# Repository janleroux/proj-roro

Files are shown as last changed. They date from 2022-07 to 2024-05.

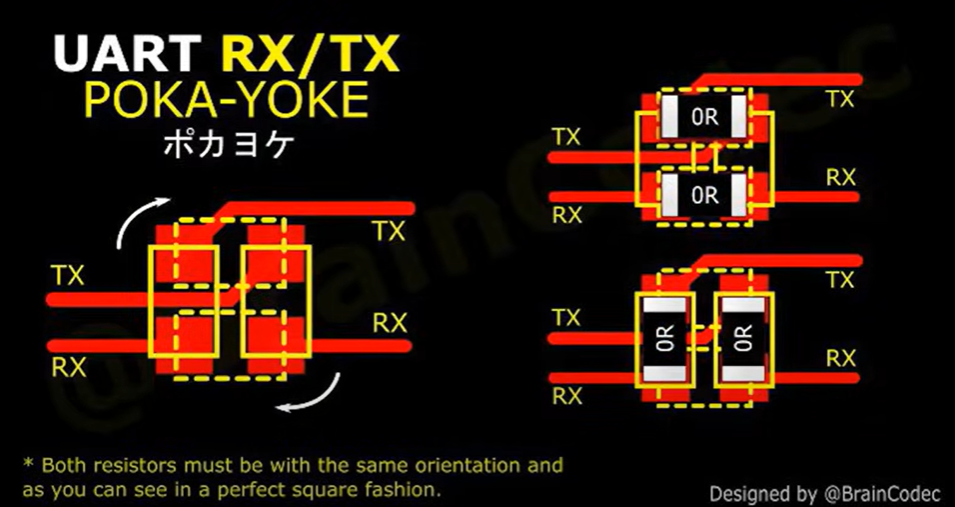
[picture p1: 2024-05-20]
linki/linki 1.0/media/Uart_mixups_fix.png

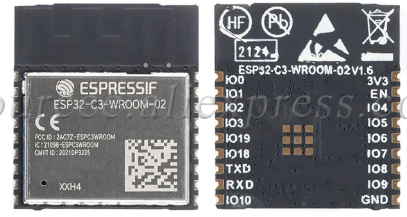
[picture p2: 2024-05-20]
linki/linki 1.0/media/WROOM-02-H4.png

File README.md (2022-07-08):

# RORO10

## Overview
The LERU Roro v1.0 is a small wireless transceiver module offers a comprehensive mix of long range, low power consumption and secure data transmission.It is designed to facilitate developers to quickly move the same platform they use for prototyping to industrial level LoRa and IoT solutions. It offers all the core functions that will solve 99% of the requirements to turn an idea to reality. It is easy to program, create and connect your things everywhere. 

The Roro wireless part is based on a RFM95 module which allows the user to send data and reach extremely long ranges at low data-rates. It provides ultra-long range spread spectrum communication and high interference immunity whilst minimising current consumption. It targets professional wireless sensor network applications such as irrigation systems, smart metering, smart cities, smartphone detection, building automation, to name a few.

Roro's mcu part use an ESP32 module from Espressif Systems. The ESP32 is a well known, widely used ultra-low-power microcontroller that incorporate connectivity options such as Wi-Fi and Bluetooth. It offers two CPU cores that can be individually controlled,and the CPU clock frequency is adjustable from 80 MHz to 240 MHz. The chip also has a low-powerco-processor that can be used instead of the CPU to save power while performing tasks that do not require muchcomputing power, such as monitoring of peripherals. ESP32 integrates a rich set of peripherals, ranging fromcapacitive touch sensors, Hall sensors, SD card interface, Ethernet, high-speed SPI, UART, I²S and I²C

[Roro Wiki](https://github.com/janleroux/leru-roro/wiki)

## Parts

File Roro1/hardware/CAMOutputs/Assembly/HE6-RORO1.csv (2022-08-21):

Qty | Value | Device | Package | Parts | Description
1 |  | CONN_01PTH_NO_SILK_YES_STOP | 1X01_NO_SILK | J1 | Single connection point. Often used as Generic Header-pin footprint for 0.1 inch spaced/style header connections
2 |  | CONN_14NO_SILK | 1X14_NO_SILK | J3, J4 | Multi connection point. Often used as Generic Header-pin footprint for 0.1 inch spaced/style header connections
1 |  | MICROBUILDER_ANTENNA_U.FL | MICROBUILDER_U.FL | ANT | U.FL Antenna Connector
1 |  | RFM69HCW_SMT | RFMHCW_SMT | U1 | RFM69HCW - ISM Band RF Transceiver
4 | 100k | RES0805-RES | RES | R1, R3, R4, R9 | Resistor
3 | 100nF | CAP0805 | CAP | C10, C11, C12 | Capacitor
2 | 10K | RES0805-RES | RES | R2, R5 | Resistor
1 | 10uF | CAP0805 | CAP | C2 | Capacitor
1 | 1nF | CAP0805 | CAP | C1 | Capacitor
1 | 22uF | CAP0805 | CAP | C9 | Capacitor
1 | ESP32-WROOM-32(8MB) | ESP32-WROOM-32(8MB) | MODULE_ESP32-WROOM-32(8MB) | U3 | WIFI MODULE 64 MBITS SPI FLASH
1 | LERU_LOGO_9MM | LERU_LOGO_9MM | LERU_LOGO_9MM | U$9
1 | MBR120 | DIODESOD123 | DIODE | D2 | DIODE
2 | MOMENTARY-SWITCH-SPST-SMD-RIGHT-ANGLE | MOMENTARY-SWITCH-SPST-SMD-RIGHT-ANGLE | TACTILE_SWITCH_SMD_RIGHT_ANGLE | PGM, RST | Momentary Switch (Pushbutton) - SPST
1 | WS2812B | WS2812B | WS2812B | NEO | WS2812B SMD addressable RGB LED

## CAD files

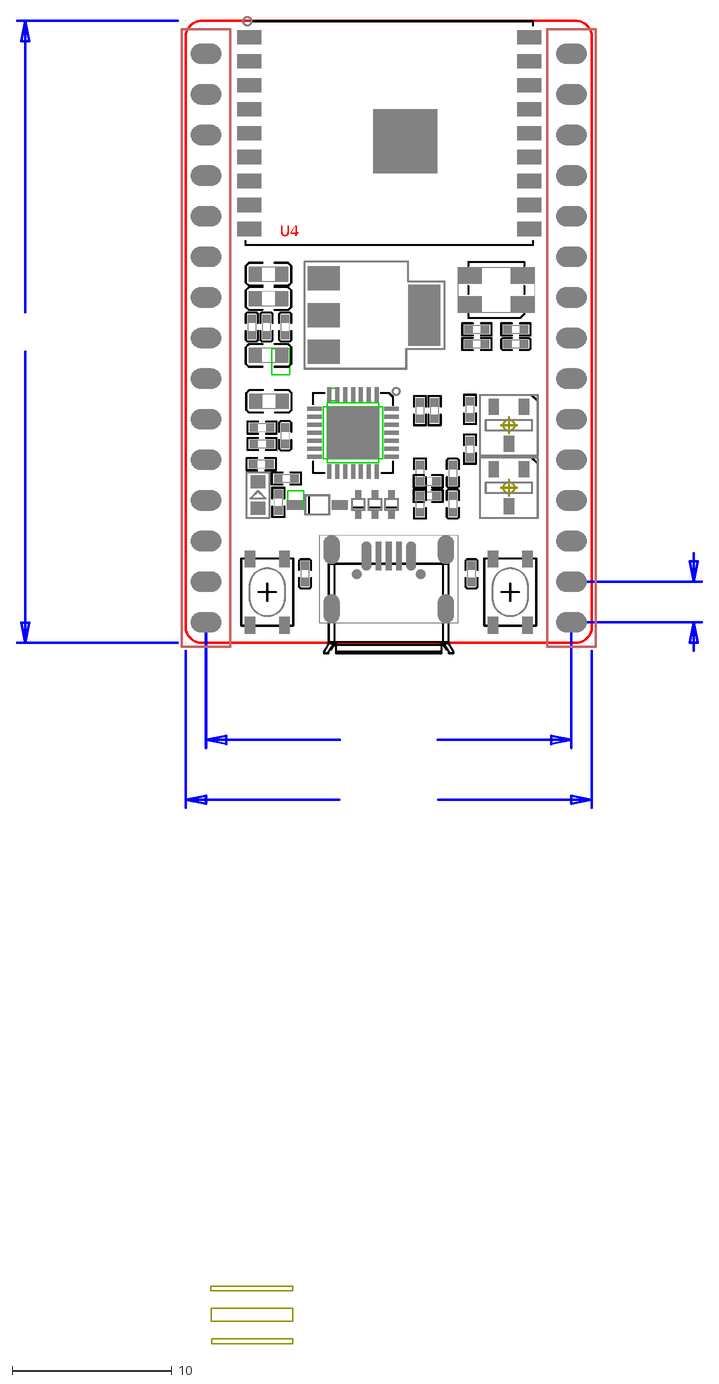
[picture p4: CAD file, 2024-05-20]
linki/linki 1.0/media/DXF_ESP32-C3-DevKitC-02_V1_1_20210121AA.dxf
U4

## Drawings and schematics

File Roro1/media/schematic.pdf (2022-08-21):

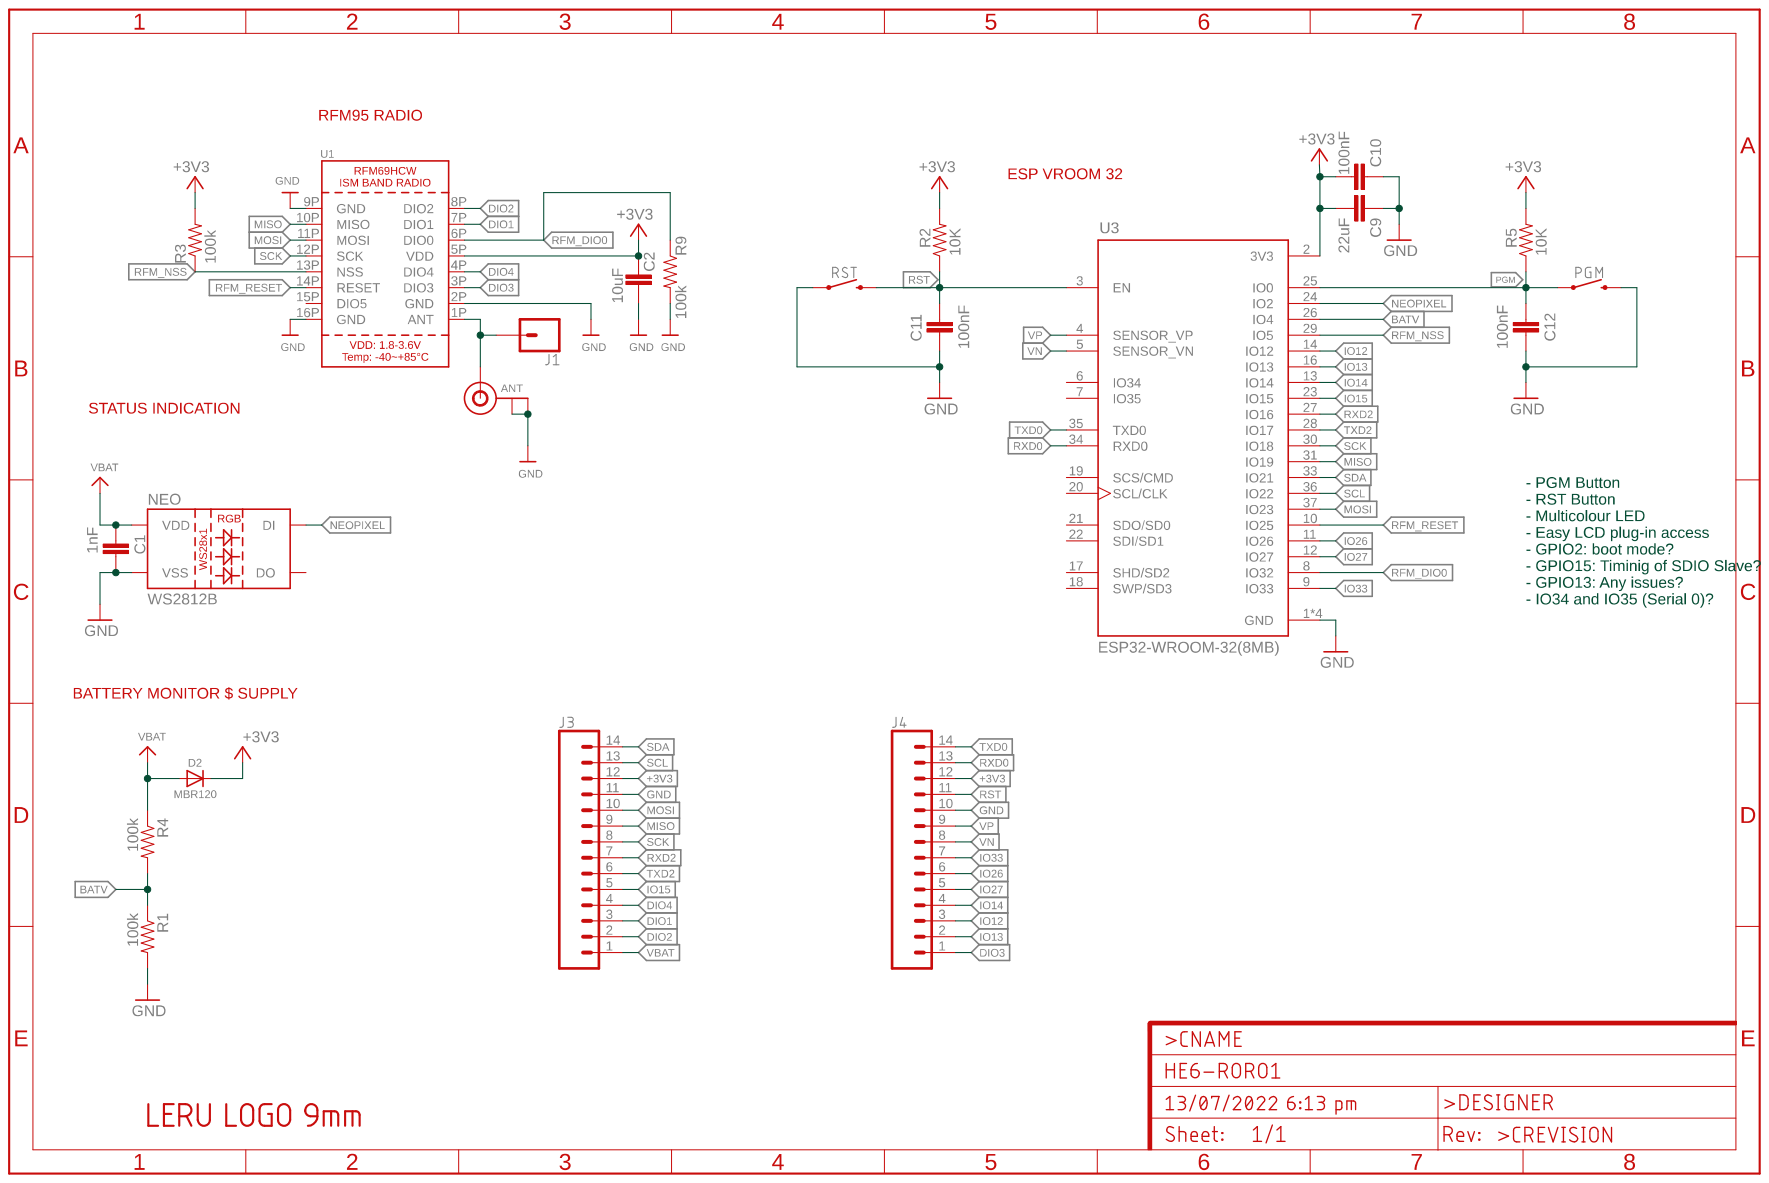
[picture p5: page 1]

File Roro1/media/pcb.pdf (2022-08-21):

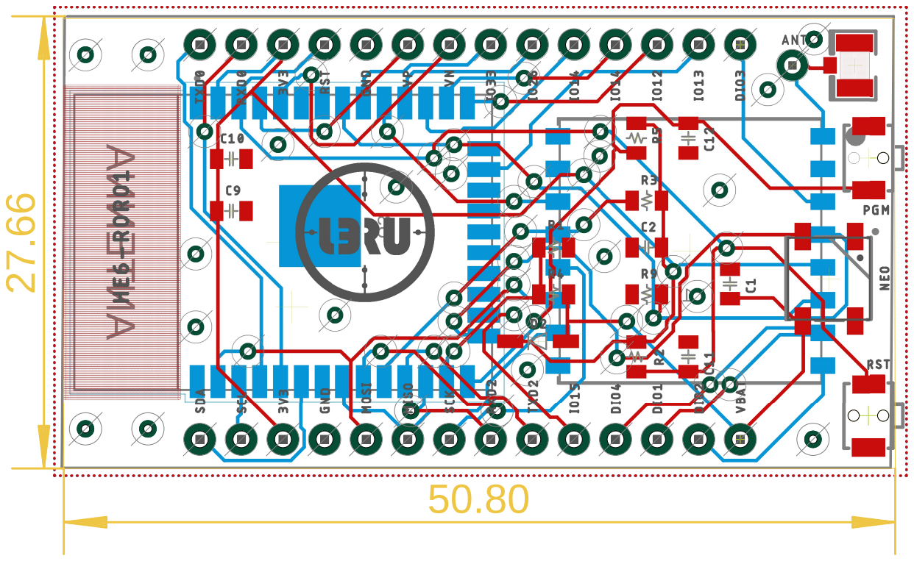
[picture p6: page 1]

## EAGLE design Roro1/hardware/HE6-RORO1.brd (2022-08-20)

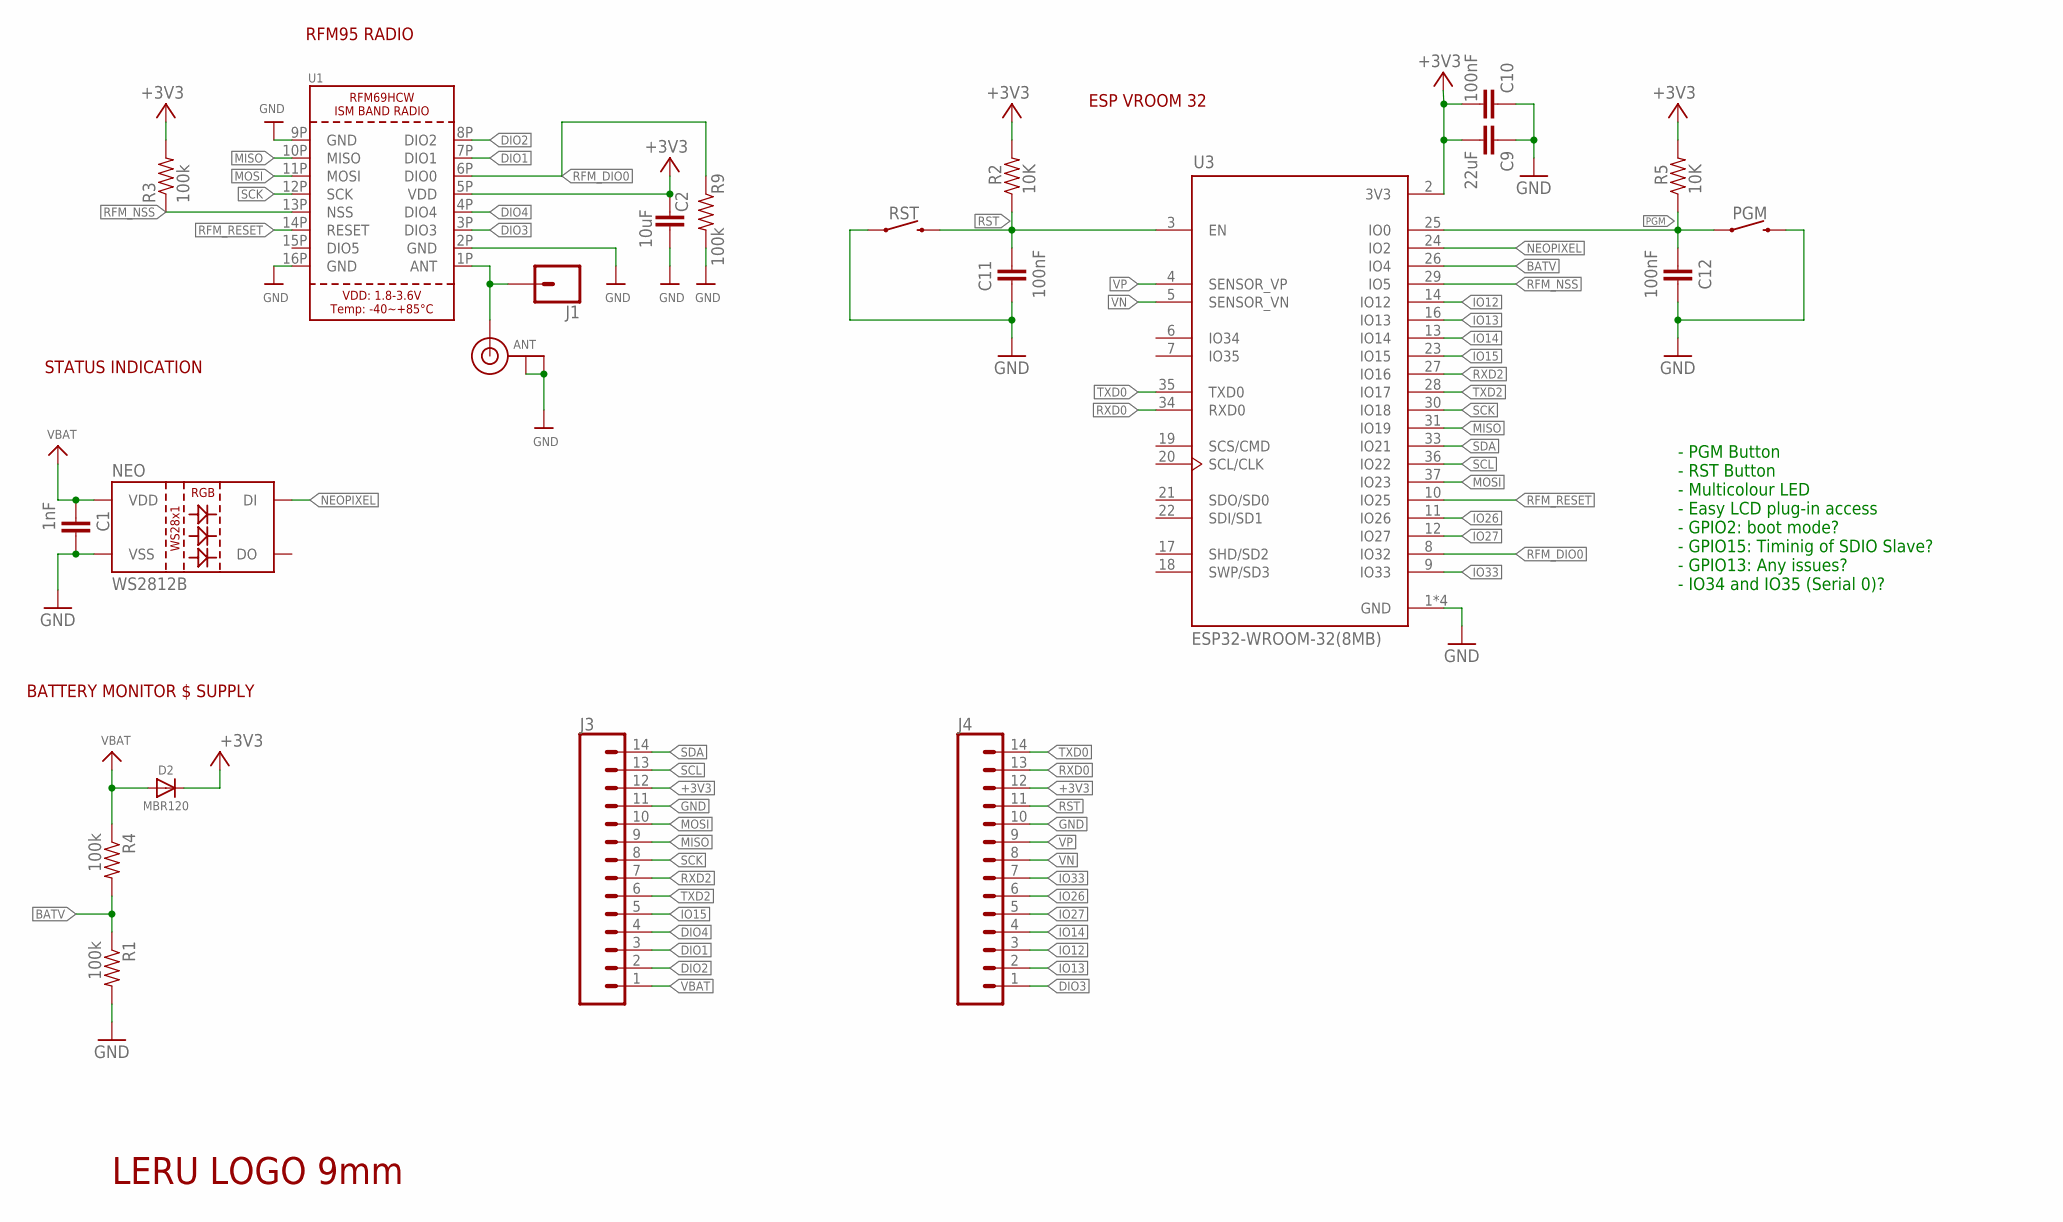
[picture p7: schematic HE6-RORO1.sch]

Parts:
ANT: MICROBUILDER_ANTENNA_U.FL; MICROBUILDER_U.FL
C1: 1nF; CAP
C2: 10uF; CAP
C9: 22uF; CAP
C10, C11, C12: 100nF; CAP
D2: MBR120; DIODE
J1: CONN_01PTH_NO_SILK_YES_STOP; 1X01_NO_SILK
J3, J4: CONN_14NO_SILK; 1X14_NO_SILK
NEO: WS2812B
PGM: MOMENTARY-SWITCH-SPST-SMD-RIGHT-ANGLE; TACTILE_SWITCH_SMD_RIGHT_ANGLE
R1, R3, R4, R9: 100k; RES
R2, R5: 10K; RES
RST: MOMENTARY-SWITCH-SPST-SMD-RIGHT-ANGLE; TACTILE_SWITCH_SMD_RIGHT_ANGLE
U1: RFM69HCW_SMT; RFMHCW_SMT
U3: ESP32-WROOM-32(8MB); MODULE_ESP32-WROOM-32(8MB)
U$9: LERU_LOGO_9MM

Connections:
+3V3: C2.1, C9.2, C10.2, D2.1 (C), J3.12, J4.12, R2.2, R3.2, R5.2, U1.5P (VDD), U3.2 (3V3)
BATV: R1.1, R4.2, U3.26 (IO4)
DIO1: J3.3, U1.7P (DIO1)
DIO2: J3.2, U1.8P (DIO2)
DIO3: J4.1, U1.3P (DIO3)
DIO4: J3.4, U1.4P (DIO4)
GND: ANT.1 (GND), ANT.2 (GND), C1.1, C2.2, C9.1, C10.1, C11.1, C12.1, J3.11, J4.10, NEO.3 (VSS), PGM.2, R1.2, R9.2, RST.1, U1.2P (GND), U1.9P (GND), U1.16P (GND), U3.1 (GND), U3.15 (GND), U3.38 (GND), U3.39 (GND)
IO12: J4.3, U3.14 (IO12)
IO13: J4.2, U3.16 (IO13)
IO14: J4.4, U3.13 (IO14)
IO15: J3.5, U3.23 (IO15)
IO26: J4.6, U3.11 (IO26)
IO27: J4.5, U3.12 (IO27)
IO33: J4.7, U3.9 (IO33)
MISO: J3.9, U1.10P (MISO), U3.31 (IO19)
MOSI: J3.10, U1.11P (MOSI), U3.37 (IO23)
unnamed: ANT.3 (SIGNAL), J1.1, U1.1P (ANT)
NEOPIXEL: NEO.4 (DI), U3.24 (IO2)
PGM: C12.2, PGM.1, R5.1, U3.25 (IO0)
RFM_DIO0: R9.1, U1.6P (DIO0), U3.8 (IO32)
RFM_NSS: R3.1, U1.13P (NSS), U3.29 (IO5)
RFM_RESET: U1.14P (RESET), U3.10 (IO25)
RST: C11.2, J4.11, R2.1, RST.2, U3.3 (EN)
RXD0: J4.13, U3.34 (RXD0)
RXD2: J3.7, U3.27 (IO16)
SCK: J3.8, U1.12P (SCK), U3.30 (IO18)
SCL: J3.13, U3.36 (IO22)
SDA: J3.14, U3.33 (IO21)
TXD0: J4.14, U3.35 (TXD0)
TXD2: J3.6, U3.28 (IO17)
VBAT: C1.2, D2.2 (A), J3.1, NEO.1 (VDD), R4.1
VN: J4.8, U3.5 (SENSOR_VN)
VP: J4.9, U3.4 (SENSOR_VP)

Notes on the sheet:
RFM95 RADIO
ESP VROOM 32
BATTERY MONITOR $ SUPPLY
- PGM Button - RST Button - Multicolour LED - Easy LCD plug-in access - GPIO2: boot mode? - GPIO15: Timinig of SDIO Slave? - GPIO13: Any issues? - IO34 and IO35 (Serial 0)?
STATUS INDICATION

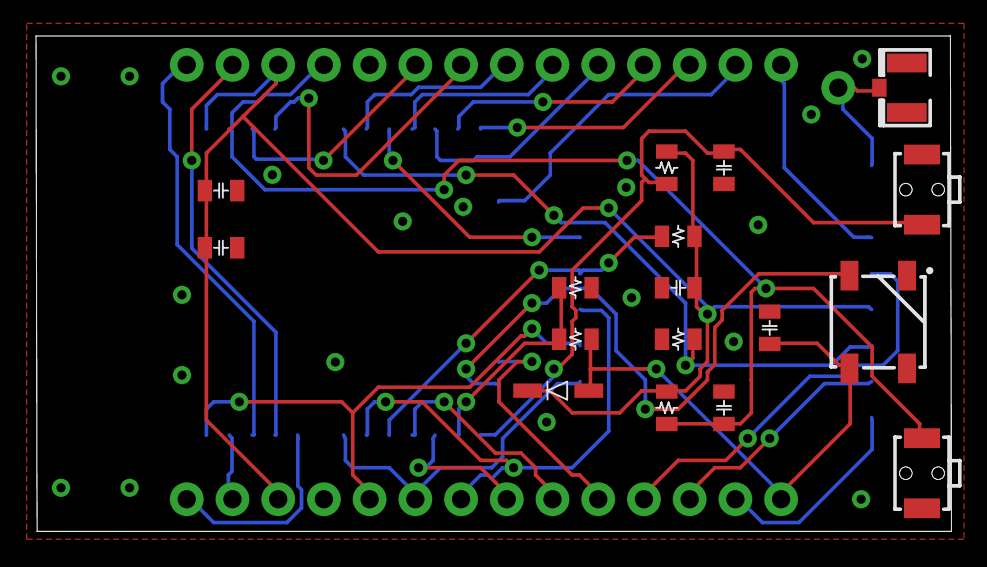
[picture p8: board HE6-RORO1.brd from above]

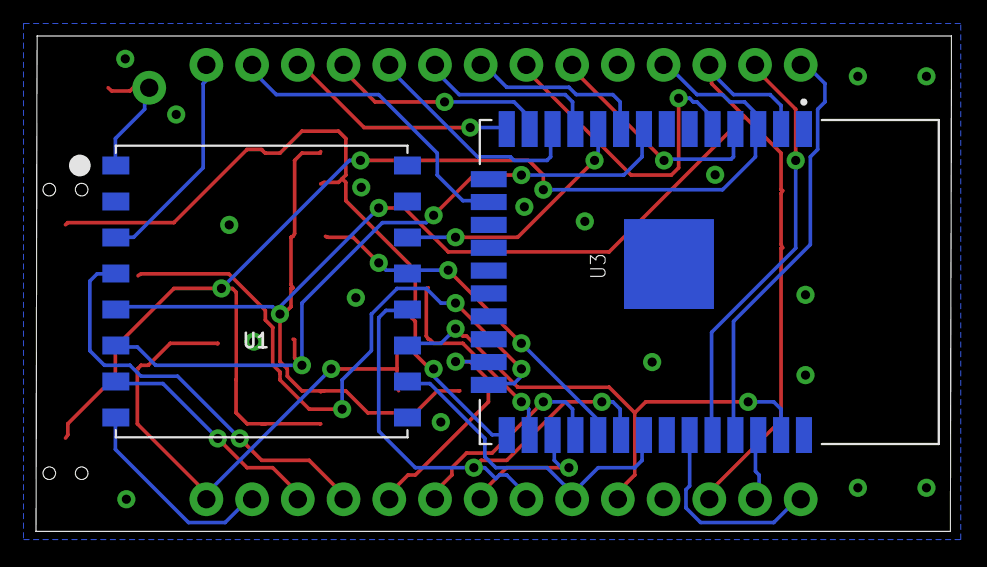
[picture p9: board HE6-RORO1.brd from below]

Board: 2 copper layers, 50.9 x 27.5 mm, 23 parts (2 on the bottom side), 33 nets.

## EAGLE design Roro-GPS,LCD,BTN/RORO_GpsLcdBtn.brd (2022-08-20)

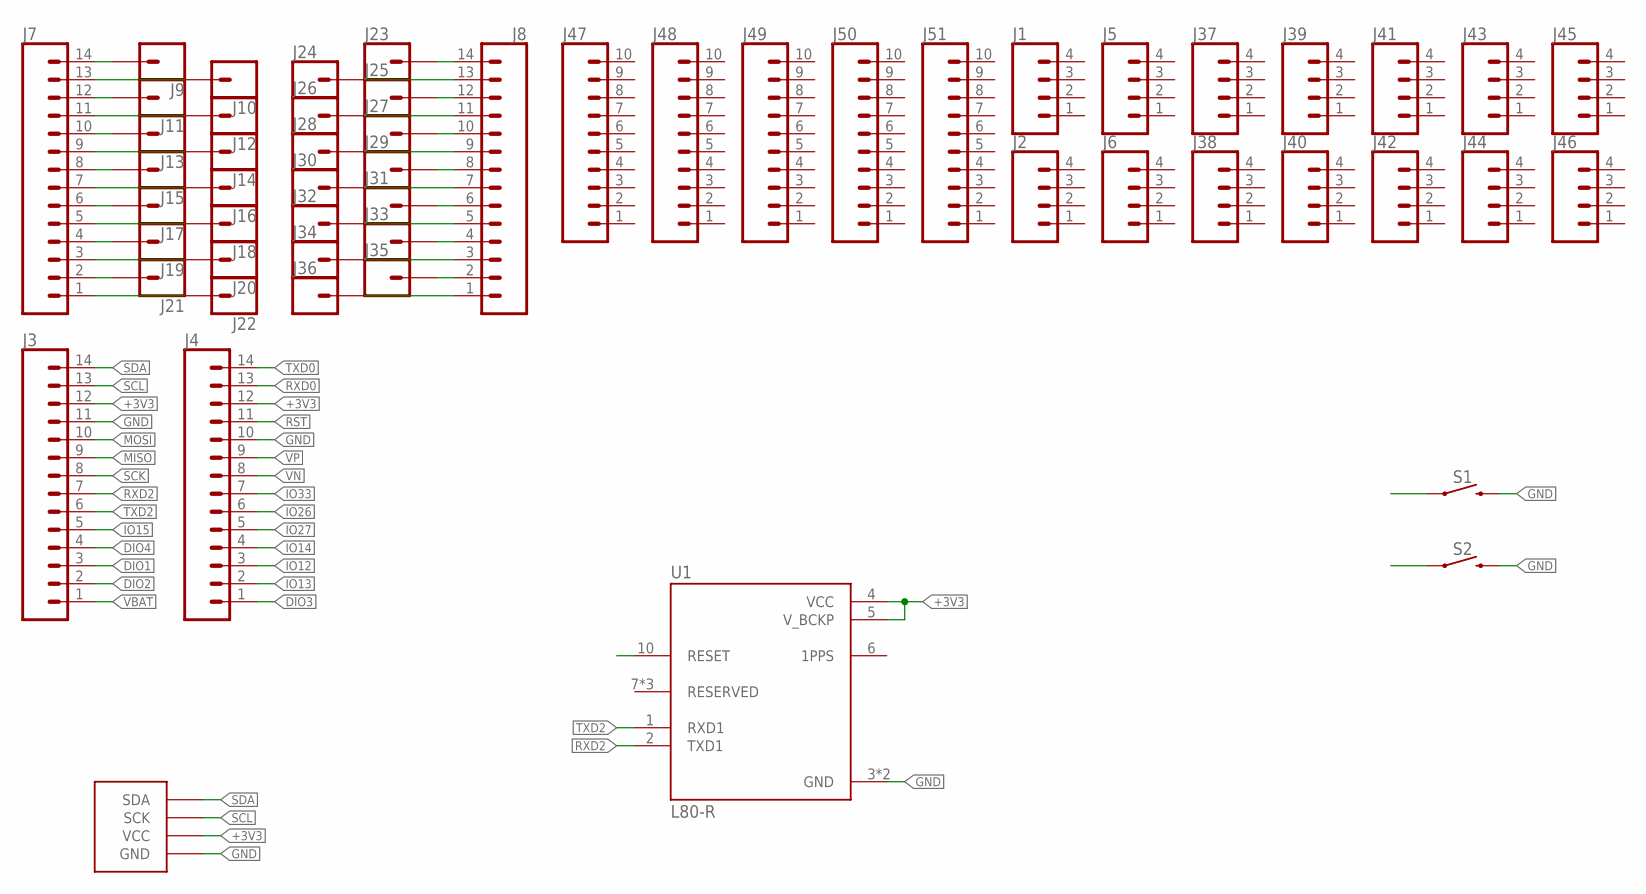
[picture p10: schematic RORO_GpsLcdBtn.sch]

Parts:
J1, J2, J5, J6, J37, J38, J39, J40, J41, J42, J43, J44, J45, J46: CONN_041X04_NO_SILK; 1X04_NO_SILK
J3, J4, J7, J8: CONN_14NO_SILK; 1X14_NO_SILK
J9, J10, J11, J12, J13, J14, J15, J16, J17, J18, J19, J20, J21, J22, J23, J24, J25, J26, J27, J28, J29, J30, J31, J32, J33, J34, J35, J36: CONN_01PTH_NO_SILK_KIT; 1X01NS_KIT
J47, J48, J49, J50, J51: CONN_10NO_SILK_PTH_FEMALE; 1X10_NO_SILK
S1, S2: MOMENTARY-SWITCH-SPST-SMD-6.0X3.5MM; TACTILE_SWITCH_SMD_6.0X3.5MM
U1: L80-R; XCVR_L80-R
U$1: 128X64_I2COLED

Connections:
+3V3: J3.12, J4.12, U1.4 (VCC), U1.5 (V_BCKP), U$1.P$3 (VCC)
DIO1: J3.3
DIO2: J3.2
DIO3: J4.1
DIO4: J3.4
GND: J3.11, J4.10, S1.2, S2.2, U1.3 (GND), U1.12 (GND), U$1.P$4 (GND)
IO12: J4.3
IO13: J4.2
IO14: J4.4
IO15: J3.5
IO26: J4.6
IO27: J4.5
IO33: J4.7
MISO: J3.9
MOSI: J3.10
unnamed: J7.14, J9.1
unnamed: J7.13, J10.1
unnamed: J7.12, J11.1
unnamed: J7.11, J12.1
unnamed: J7.10, J13.1
unnamed: J7.9, J14.1
unnamed: J7.8, J15.1
unnamed: J7.7, J16.1
unnamed: J7.6, J17.1
unnamed: J7.5, J18.1
unnamed: J7.4, J19.1
unnamed: J7.3, J20.1
unnamed: J7.2, J21.1
unnamed: J7.1, J22.1
unnamed: J8.14, J23.1
unnamed: J8.13, J24.1
unnamed: J8.12, J25.1
unnamed: J8.11, J26.1
unnamed: J8.10, J27.1
unnamed: J8.9, J28.1
unnamed: J8.8, J29.1
unnamed: J8.7, J30.1
unnamed: J8.6, J31.1
unnamed: J8.5, J32.1
unnamed: J8.4, J33.1
unnamed: J8.3, J34.1
unnamed: J8.2, J35.1
unnamed: J8.1, J36.1
RST: J4.11
RXD0: J4.13
RXD2: J3.7, U1.2 (TXD1)
SCK: J3.8
SCL: J3.13, U$1.P$2 (SCK)
SDA: J3.14, U$1.P$1 (SDA)
TXD0: J4.14
TXD2: J3.6, U1.1 (RXD1)
VBAT: J3.1
VN: J4.8
VP: J4.9

Board: 2 copper layers, 55 parts (0 on the bottom side), 34 nets, no tracks yet.

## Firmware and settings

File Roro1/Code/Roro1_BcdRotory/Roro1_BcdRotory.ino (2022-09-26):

#define pin1  GPIO_NUM_36
#define pin8  GPIO_NUM_39
#define pin2  GPIO_NUM_26
#define pin4  GPIO_NUM_27

void setup() {
  //setup serial
  Serial.begin(115200); 
  Serial.println("BCD values: ");

  //pin modes
  pinMode(pin1, INPUT);
  pinMode(pin2, INPUT);
  pinMode(pin4, INPUT);
  pinMode(pin8, INPUT);

}

void loop() {
  // put your main code here, to run repeatedly:
  int a = digitalRead(pin1);
  int b = digitalRead(pin2);
  int c = digitalRead(pin4);
  int d = digitalRead(pin8);
  
  Serial.print(a);
  Serial.print(" ");
  Serial.print(b);
  Serial.print(" ");
  Serial.print(c);
  Serial.print(" ");
  Serial.println(d);
  delay(5000);
}

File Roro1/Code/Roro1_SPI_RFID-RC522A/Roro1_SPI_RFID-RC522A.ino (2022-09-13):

/*
 * --------------------------------------------------------------------------------------------------------------------
 * Example sketch/program showing how to read new NUID from a PICC to serial.
 * --------------------------------------------------------------------------------------------------------------------
 * This is a MFRC522 library example; for further details and other examples see: https://github.com/miguelbalboa/rfid
 * 
 * Example sketch/program showing how to the read data from a PICC (that is: a RFID Tag or Card) using a MFRC522 based RFID
 * Reader on the Arduino SPI interface.
 * 
 * When the Arduino and the MFRC522 module are connected (see the pin layout below), load this sketch into Arduino IDE
 * then verify/compile and upload it. To see the output: use Tools, Serial Monitor of the IDE (hit Ctrl+Shft+M). When
 * you present a PICC (that is: a RFID Tag or Card) at reading distance of the MFRC522 Reader/PCD, the serial output
 * will show the type, and the NUID if a new card has been detected. Note: you may see "Timeout in communication" messages
 * when removing the PICC from reading distance too early.
 * 
 * @license Released into the public domain.
 * 
 * Typical pin layout used:
 * -----------------------------------------------------------------------------------------
 *             MFRC522      Arduino       Arduino   Arduino    Arduino          Arduino
 *             Reader/PCD   Uno/101       Mega      Nano v3    Leonardo/Micro   Pro Micro
 * Signal      Pin          Pin           Pin       Pin        Pin              Pin
 * -----------------------------------------------------------------------------------------
 * RST/Reset   RST          9             5         D9         RESET/ICSP-5     RST
 * SPI SS      SDA(SS)      10            53        D10        10               10
 * SPI MOSI    MOSI         11 / ICSP-4   51        D11        ICSP-4           16
 * SPI MISO    MISO         12 / ICSP-1   50        D12        ICSP-1           14
 * SPI SCK     SCK          13 / ICSP-3   52        D13        ICSP-3           15
 *
 * More pin layouts for other boards can be found here: https://github.com/miguelbalboa/rfid#pin-layout
 */

#include <SPI.h>
#include <MFRC522.h>

#define SS_PIN 12
#define RST_PIN 13
 
MFRC522 rfid(SS_PIN, RST_PIN); // Instance of the class

MFRC522::MIFARE_Key key; 

// Init array that will store new NUID 
byte nuidPICC[4];

void setup() { 
  Serial.begin(115200);
  SPI.begin(); // Init SPI bus
  rfid.PCD_Init(); // Init MFRC522 

  for (byte i = 0; i < 6; i++) {
    key.keyByte[i] = 0xFF;
  }

  Serial.println(F("This code scan the MIFARE Classsic NUID."));
  Serial.print(F("Using the following key:"));
  printHex(key.keyByte, MFRC522::MF_KEY_SIZE);
}
 
void loop() {

  // Reset the loop if no new card present on the sensor/reader. This saves the entire process when idle.
  if ( ! rfid.PICC_IsNewCardPresent())
    return;

  // Verify if the NUID has been readed
  if ( ! rfid.PICC_ReadCardSerial())
    return;

  Serial.print(F("PICC type: "));
  MFRC522::PICC_Type piccType = rfid.PICC_GetType(rfid.uid.sak);
  Serial.println(rfid.PICC_GetTypeName(piccType));

  // Check is the PICC of Classic MIFARE type
  if (piccType != MFRC522::PICC_TYPE_MIFARE_MINI &&  
    piccType != MFRC522::PICC_TYPE_MIFARE_1K &&
    piccType != MFRC522::PICC_TYPE_MIFARE_4K) {
    Serial.println(F("Your tag is not of type MIFARE Classic."));
    return;
  }

  if (rfid.uid.uidByte[0] != nuidPICC[0] || 
    rfid.uid.uidByte[1] != nuidPICC[1] || 
    rfid.uid.uidByte[2] != nuidPICC[2] || 
    rfid.uid.uidByte[3] != nuidPICC[3] ) {
    Serial.println(F("A new card has been detected."));

    // Store NUID into nuidPICC array
    for (byte i = 0; i < 4; i++) {
      nuidPICC[i] = rfid.uid.uidByte[i];
    }
   
    Serial.println(F("The NUID tag is:"));
    Serial.print(F("In hex: "));
    printHex(rfid.uid.uidByte, rfid.uid.size);
    Serial.println();
    Serial.print(F("In dec: "));
    printDec(rfid.uid.uidByte, rfid.uid.size);
    Serial.println();
  }
  else Serial.println(F("Card read previously."));

  // Halt PICC
  rfid.PICC_HaltA();

  // Stop encryption on PCD
  rfid.PCD_StopCrypto1();
}


/**
 * Helper routine to dump a byte array as hex values to Serial. 
 */
void printHex(byte *buffer, byte bufferSize) {
  for (byte i = 0; i < bufferSize; i++) {
    Serial.print(buffer[i] < 0x10 ? " 0" : " ");
    Serial.print(buffer[i], HEX);
  }
}

/**
 * Helper routine to dump a byte array as dec values to Serial.
 */
void printDec(byte *buffer, byte bufferSize) {
  for (byte i = 0; i < bufferSize; i++) {
    Serial.print(buffer[i] < 0x10 ? " 0" : " ");
    Serial.print(buffer[i], DEC);
  }
}

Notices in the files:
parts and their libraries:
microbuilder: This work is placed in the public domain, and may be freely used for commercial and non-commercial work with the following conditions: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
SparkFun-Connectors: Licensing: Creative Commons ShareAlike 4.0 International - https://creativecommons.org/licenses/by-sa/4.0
